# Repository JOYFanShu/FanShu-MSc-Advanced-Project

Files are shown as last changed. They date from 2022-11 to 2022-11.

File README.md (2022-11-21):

<h3 align="center">
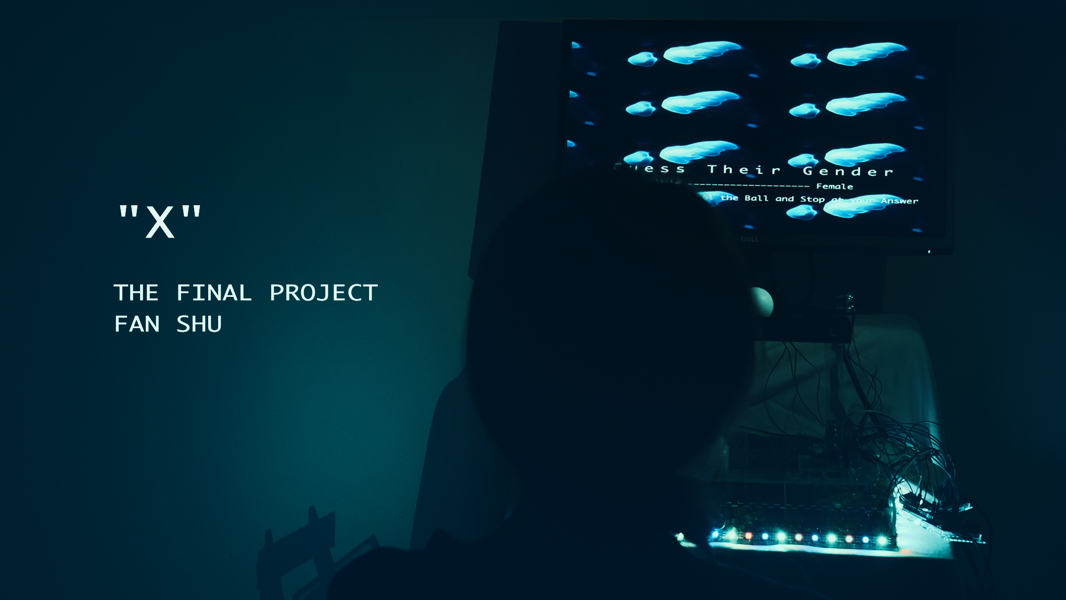
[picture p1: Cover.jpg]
  
</h3>

# “X”-MSc-Advanced-Project      
FAN SHU 20011098          
          
🔗：* [Github for Advanced Project](https://github.com/JOYFanShu/FanShu-MSc-Advanced-Project)
                                                 
## Concept
Inevitably, in any scenario, robots, or artificial intelligence, have gradually become integrated into human society. Robotics experts consider some attributes, such as robot gender. Robots have no gender - they are metal, plastic and silicon, and are full of "1s" and "0s". But humans have always been able to make their judgements by cues such as appearance, colour, personality and voice. The problem for robot designers today is to create fairer gender norms that challenge current gender stereotypes. Better gender norms in robot society will also feed back into human society.
The scales of robotic gender do not exist, But it has done its best to maintain its balance. Good human gender norms will help this 'balance' to be better maintained, and a blanket disregard and misuse of stereotypes will reflect badly on it.        
<h3 align="center">
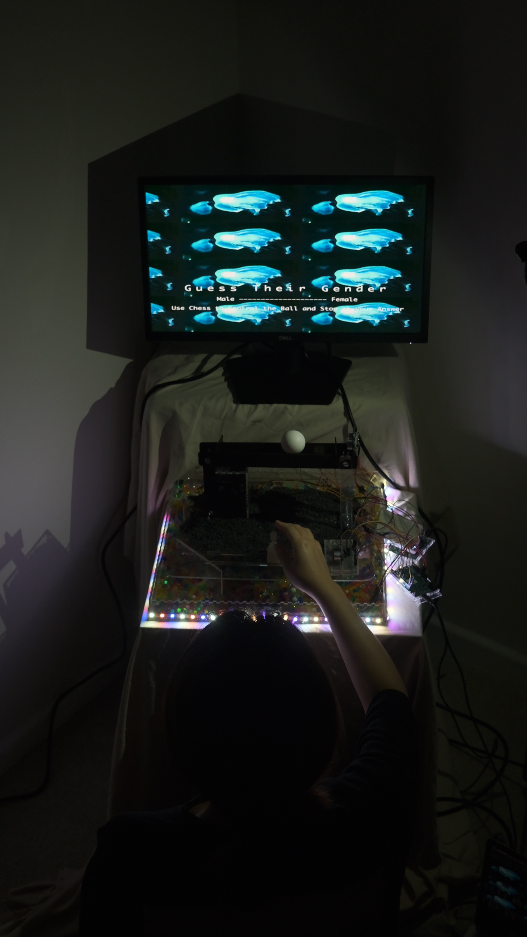
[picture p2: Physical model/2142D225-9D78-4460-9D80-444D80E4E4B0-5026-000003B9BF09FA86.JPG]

</h3>

## How It Works        
The project "X" aims to visualise the gender dilemma faced by robots, with a beam, a ball and a machine-generated digital jellyfish as the centre of vision.
1. When the user approaches the installation, LEDs will light up.           
2. A video on screen plays a photo of the generated electronic jellyfish and subtitles guide the user in guessing their gender. The leftmost side is male, the rightmost is female and the position of the ball will be taken as the user's answer. The user can move the pieces to influence the servo’s angle at so that the ball stay at their ideal position. Of course the result may be unsatisfactory.               
3. When the angle of the beam reaches a certain value, the video will be distorted and glitched.   
                              
*Watch the Video*                              
Watch the Video (https://youtu.be/ViRgSTNtf5M)     
                     
## Iterative Development Blog
#### Week01&02&03
After the tutorial with Hadeel, I decided on the direction of my research on gender in robotics. I spent the first three weeks reading papers on this topic, trying to find my own research direction by pulling from existing research directions. I found 10 respondents and invited them to fill in my questionnaire.
<h3 align="center">
截屏2022-11-21 10 58 19   
</h3>
                    
After a lot of brainstorming and trial and error, I finally decided to focus on the "balance" of the device, and Hadeel recommended the PID algorithm and the accelerometer. That is how most robots self-balance.

#### Week04&05.     
During these two weeks I started writing the code and built the first simple Model One. With constant debugging it worked successfully.        
<h3 align="center">
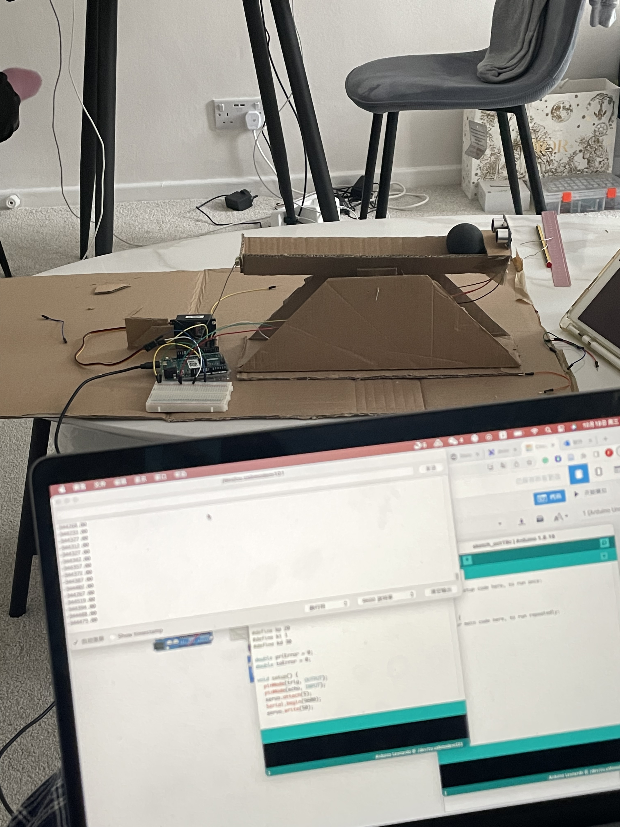
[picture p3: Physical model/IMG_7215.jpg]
  
</h3>
<h3 align="center">
  
</h3>
                                  
The interaction method bothered me. At first I envisaged a solution with a servo motor picking the ball on the beam to break the balance itself. The user could control this by sliding a resistor. But the completed circuit didn't work as perfectly as I thought it would. I started thinking about whether I could develop from the existing code to find out what was possible.                  
I planned to add another ultrasonic sensor, which would use the distance it sensed when an object was placed in front of it to prompt the servo motor to move until the distance between the ball on the beam and the ultrasonic sensor was also maintained at the same level before the motor would stop moving. If the user flicks the ball directly by hand, the ball will struggle to regain its balance, just as it did with the previous Model One.   

https://user-images.githubusercontent.com/91974159/203129030-f596dd86-e5fa-42dc-bd8c-cc4acb263dbf.mp4

#### Week06&07 
In order to enhance the sensation of the user's five senses, I was determined to create some graphics for the installation. I did not want to present the robot in a particularly straightforward way already. Therefore it was decided to use a machine-generated digital jellyfish instead. Video of a non-existent jellyfish generated using style gan3.

https://user-images.githubusercontent.com/91974159/203140845-792b3bac-99db-4006-9614-24828aaffb74.mp4

The complete interactive concept of the entire installation is beginning to take shape. Subtitles guide the user in guessing their gender. The leftmost side is male, the rightmost is female and the position of the ball will be taken as the user's answer. The user can move the pieces to influence the servo’s angle at so that the ball stay at their ideal position. Of course the result may be unsatisfactory.
Some users wanted an interactive response between the video and the physical device after trying it out, so I used touch designer as a bridge to provide serial data via an absolute orientation sensor glued to the horizontal beam structure, which was used to drive the distortion and pixelation of the video.

https://user-images.githubusercontent.com/91974159/203141936-3ee1fca4-9795-4988-a728-721c3108ac62.mp4

#### Week08&09
To make the model more aesthetically pleasing, I drew up laser cutouts. Thus was born Model Two, but along the way there were many dimensional errors and the servos were not placed high enough. With a lot of adjustments, the finished Model 3 was finally completed. Adding the light strip to the complete circuitry of the debugged Model Three.
<h3 align="center">
  
</h3>
<h3 align="center">
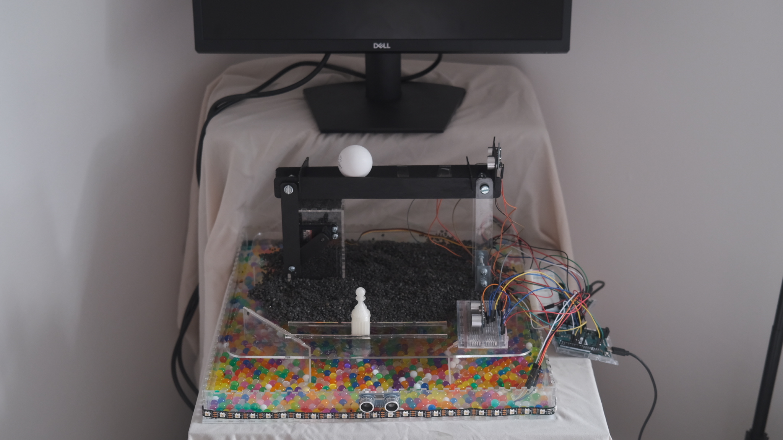
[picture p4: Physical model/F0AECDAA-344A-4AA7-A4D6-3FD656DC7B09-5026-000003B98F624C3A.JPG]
  
</h3>
<h3 align="center">
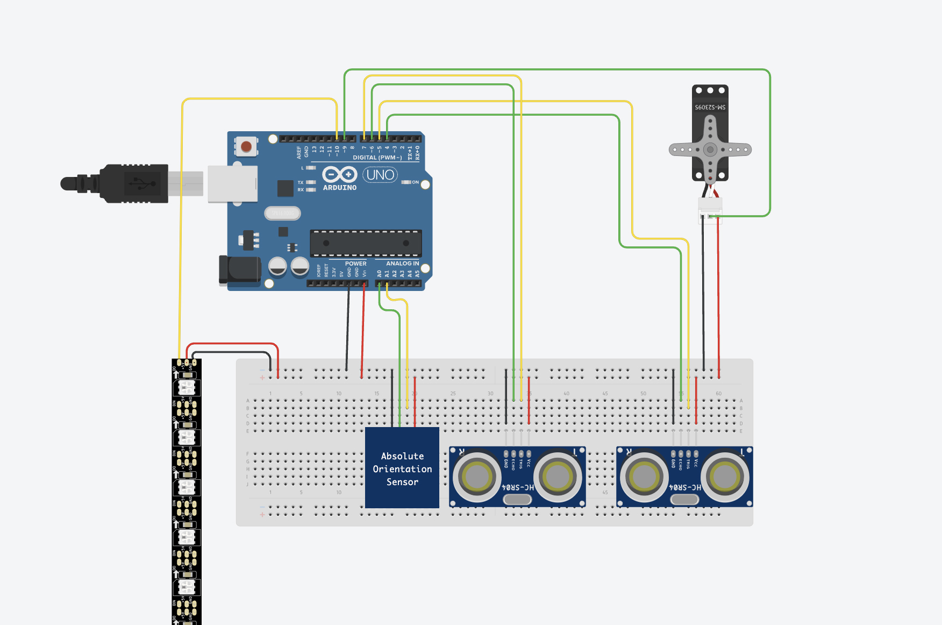
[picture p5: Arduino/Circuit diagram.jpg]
  
</h3>
 I used 3D printing to create the pieces that the participants needed to move.        
<h3 align="center">
  
</h3>  
              
#### Week10
The final week was used to shoot the video, edit it and write the essay.

Thank you for watching.😊

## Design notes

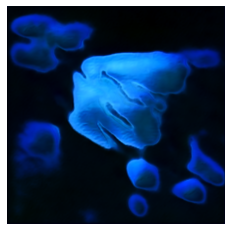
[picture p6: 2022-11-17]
Video-Machine Learning/picture/jellyfish28.png

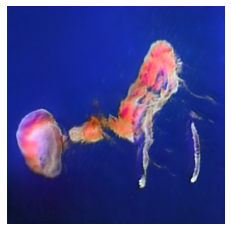
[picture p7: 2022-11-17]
Video-Machine Learning/picture/jellyfish22.png

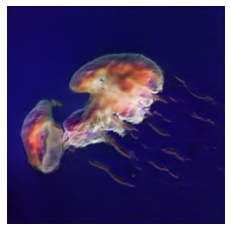
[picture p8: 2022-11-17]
Video-Machine Learning/picture/jellyfish20.png

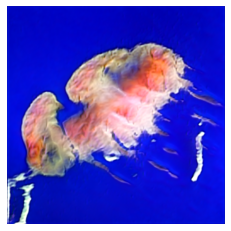
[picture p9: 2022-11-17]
Video-Machine Learning/picture/jellyfish18.png

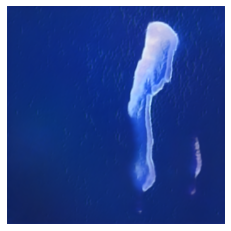
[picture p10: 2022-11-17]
Video-Machine Learning/picture/jellyfish8.png

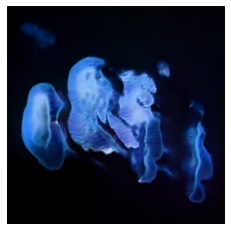
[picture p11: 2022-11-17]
Video-Machine Learning/picture/jellyfish23.png

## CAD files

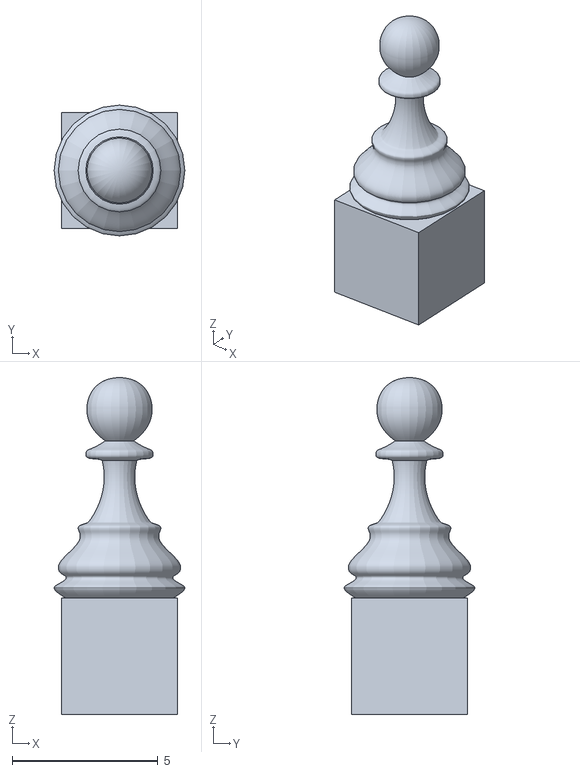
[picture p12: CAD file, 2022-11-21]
Physical model/3D printing/chess02.stl
4.49 x 4.49 x 11.6

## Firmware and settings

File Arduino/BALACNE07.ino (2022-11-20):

#include "FastLED.h"            // 此示例程序需要使用FastLED库
#define NUM_LEDS 120      /* The amount of pixels/leds you have */
#define DATA_PIN 10      /* The pin your data line is connected to */
#define LED_TYPE WS2812B /* I assume you have WS2812B leds, if not just change it to whatever you have */
#define BRIGHTNESS 180   /* Control the brightness of your leds */
#define SATURATION 255 
CRGB leds[NUM_LEDS];

#include <Servo.h>
#define Umax 66 // maximum angle of the servomotr in degrees
#define Umin -66 // minimun angle
#define Umax_rad 1.151  // maximum angle of the servomotr in radiants
#define Umin_rad -1.151 // minimun angle
#define T 0.09 // sampling time

const int echoPin1= 12; 
const int trigPin1= 11;
const int echoPin2= 6; 
const int trigPin2= 7;  
const int echoPin3= 5; 
const int trigPin3= 4;  

Servo servo;                         

double setpoint, setpoint_prec;  // In meters : 30cm --> 0.3m
double y, y_prec;
double error;
double P, I, D, U;
double I_prec=0, U_prec=0, D_prec=0;        
boolean Saturation = false;
 
double Kp = 1.7 ; 
double Ki = 0.1 ; 
double Kd = 0.4 ;  
float measure_1 (void);
float measure_2 (void);
void move_servo(int);

void setup() {

   Serial.begin(9600);
   
   pinMode(trigPin1, OUTPUT);
   pinMode(echoPin1, INPUT);
   pinMode(trigPin2, OUTPUT);
   pinMode(echoPin2, INPUT);
   pinMode(trigPin3, OUTPUT);
   pinMode(echoPin3, INPUT);
   FastLED.addLeds<LED_TYPE, DATA_PIN>(leds, NUM_LEDS);
   
   servo.attach(9);
      
   delay(100); 
   move_servo(90);
   delay(200);
   setpoint_prec = measure_2();  // cube
   delay(100);
   y_prec = measure_1();  // cart
   delay(100);
   
}

void loop() {
   
   setpoint = measure_2();  // distance of the cube from the sensor ( meters )
   setpoint = 0.53*setpoint + 0.47*setpoint_prec  ;
   
   delay(3);
   
   y = measure_1();  // distance of the cart from the sensor ( meters )   
   y =  0.53*y + 0.47*y_prec  ;   // (  alfa*y :   if alfa increases, y less attenuated and similar to the measured y  --> so the measurement is noisy but fast )
  
   delay (3);
   
   error = round( 100*(y - setpoint) )*0.01;     // meters            
   
   P = Kp*error;
   
   if ( ! Saturation )  I = I_prec + T*Ki*error;

   D = (Kd/T)*(y - y_prec);
   
   D = 0.56*D + 0.44*D_prec;    // filtering D    
   
   U = P + I + round(100*D)*0.01 ;  // U in radiants
   
   if ( U < Umin_rad)  {
                        U=Umin_rad; 
                        Saturation = true;
                       }
                   
   else if ( U > Umax_rad)  {
                             U=Umax_rad; 
                             Saturation = true;
                            }

   else     Saturation = false;                   
   
   U=round(U*180/M_PI);     // Transform U in degrees. Now I have :   -63° < U < 63°   
          
   U=map(U, Umin, Umax, 24, 156); // I map the computed value of U to the corresponding value of the servomotor
   
   if (U < 83 || U > 95 || abs(error) > 0.02 ) move_servo( round(U) );   // I continue until I have error and the control action U is greater than a threshold.
   
   delay (24);  

   //Serial.print(setpoint*100);
   //Serial.print(" ");
   //Serial.print(y*100);
   //Serial.print(" ");
   //Serial.print(U);
   //Serial.println();
   
   
   I_prec = I;
   y_prec = y;
   D_prec = D;
   setpoint_prec = setpoint; 

   
   long duration, distance;
   digitalWrite(trigPin3, LOW);
   delayMicroseconds(2);
   digitalWrite(trigPin3, HIGH);
   delayMicroseconds(10);
   digitalWrite(trigPin3, LOW);
   duration = pulseIn(echoPin3, HIGH);
   distance = (duration/2) / 29.1; 

if (distance >= 90) {
  Serial.print(distance);
  Serial.println(" cm");  
   fill_solid(leds, 120, CRGB::Black);
   FastLED.show(); 
   delay(25);
}

if (distance < 90) {
    Serial.print(distance);
    Serial.println(" cm");
    for (int j = 0; j < 255; j++) {
    for (int i = 0; i < NUM_LEDS; i++) {
      leds[i] = CHSV(i - (j * 2), SATURATION, BRIGHTNESS); /* The higher the value 4 the less fade there is and vice versa */ 
    }
    FastLED.show();
    delay(25);
    }
}    
}


float measure_1 (void) {

long durata=0;
float distanza=0; 

digitalWrite(trigPin1, LOW); 
delayMicroseconds(4); 

digitalWrite(trigPin1, HIGH);
delayMicroseconds(10);
 
digitalWrite(trigPin1, LOW);

durata = pulseIn(echoPin1, HIGH);
distanza = (float)durata/58.2;
//delay(30);
//Serial.print("\tDistance01: ");
//Serial.print(distanza);

if (distanza > 42) distanza=43;
else if (distanza < 0) distanza=0;

return 0.01*(distanza-1.5+0.5);   // meters   

}

float measure_2 (void) {

long durata=0;
float distanza=0; 

digitalWrite(trigPin2, LOW); 
delayMicroseconds(4); 

digitalWrite(trigPin2, HIGH);
delayMicroseconds(10);
 
digitalWrite(trigPin2, LOW);

durata = pulseIn(echoPin2, HIGH);
distanza = (float)durata/58.2;
delay(30);
//Serial.print("\tDistance02: ");
//Serial.print(distanza);
//Serial.print("\t\t");

if (distanza > 42) distanza=43;
else if (distanza < 0) distanza=0;

return 0.01*(distanza+2);   // meters     ( +2 to measure the center of the cube )

} 

void move_servo(int u) {
  
servo.write(u-map(u, 30, 70, 14, 3));

}

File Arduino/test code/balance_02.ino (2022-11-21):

/*PID controller system with Arduino.
 * http://srituhobby.com
 */
 
#include <Wire.h>
#include <Adafruit_Sensor.h>
#include <Adafruit_BNO055.h>
#include <utility/imumaths.h>
#include <Servo.h>
#include <PID_v2.h>
Servo servo;

#define trig 4
#define echo 5

#define kp 60
#define ki 0
#define kd 0
#define BNO055_SAMPLERATE_DELAY_MS (100)

Adafruit_BNO055 bno = Adafruit_BNO055(-1, 0x28);
double priError = 0;
double toError = 0;

void setup() {
  pinMode(trig, OUTPUT);
  pinMode(echo, INPUT);
  servo.attach(9);
  Serial.begin(9600);
  servo.write(50);
  
  Serial.println("Orientation Sensor Raw Data Test"); Serial.println("");

  /* Initialise the sensor */
  if(!bno.begin())
  {
    /* There was a problem detecting the BNO055 ... check your connections */
    Serial.print("Ooops, no BNO055 detected ... Check your wiring or I2C ADDR!");
    while(1);
  }

  delay(1000);

  /* Display the current temperature */
  int8_t temp = bno.getTemp();
  Serial.print("Current Temperature: ");
  Serial.print(temp);
  Serial.println(" C");
  Serial.println("");

  bno.setExtCrystalUse(true);

  Serial.println("Calibration status values: 0=uncalibrated, 3=fully calibrated");

}
void loop() {
  PID();
  //  int a = distance();
  //  Serial.println(a);
}

long distance () {
  digitalWrite(trig, LOW);
  delayMicroseconds(4);
  digitalWrite(trig, HIGH);
  delayMicroseconds(10);
  digitalWrite(trig, LOW);

  long t = pulseIn(echo, HIGH);
  long cm = t / 29 / 2;
  return cm;
}

void PID() {
  int dis = distance();


  int setP = 15;
  double error = setP - dis;


  double Pvalue = error * kp;
  double Ivalue = toError * ki;
  double Dvalue = (error - priError) * kd;

  double PIDvalue = Pvalue + Ivalue + Dvalue;
  priError = error;
  toError += error;
 
  int Fvalue = (int)PIDvalue;


  Fvalue = map(Fvalue, -160, 160, 160, 0);


  if (Fvalue < 0) {
    Fvalue = 0;
  }
  if (Fvalue > 160) {
    Fvalue = 160;
  }

  servo.write(Fvalue);

  imu::Vector<3> euler = bno.getVector(Adafruit_BNO055::VECTOR_EULER);

  /* Display the floating point data */
  Serial.print("Y:");
  Serial.print(euler.y());
  Serial.println("");
  delay(BNO055_SAMPLERATE_DELAY_MS);
}
